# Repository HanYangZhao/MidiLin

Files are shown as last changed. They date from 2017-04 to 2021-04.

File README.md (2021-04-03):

# Arduino Midi Ribbon Controller

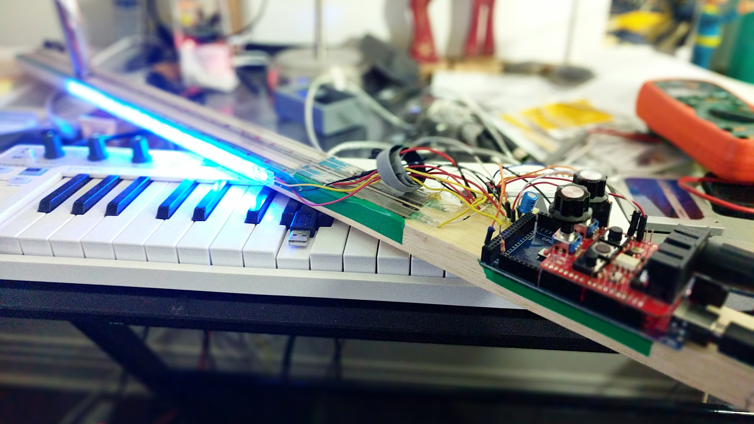
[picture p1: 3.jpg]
Demo (https://www.youtube.com/watch?v=UU3WkZmNJEc)


This project was inspired by Wintergatan's Modulin https://www.youtube.com/watch?v=MUdWeBYe3GY

## Features

* 2 x 24 quantized notes on a 50cm long neck
* Able to switch between all 7 music modes while retaining quantization
* +/- Semitone Tranpose and +/- Octave Tranpose
* Finger pressure controls modulation
* Volume controllable by adjusting the pot at the end of the neck
* LED reacts to finger position
* Pitchbend by using the analog stick

[Demo](https://youtu.be/UU3WkZmNJEc)

## Main components

* [2 x Softpot Membrane](https://www.sparkfun.com/products/8681)
* [2 x Force Sensitive Resistor](https://www.sparkfun.com/products/9674)
* 1 x Arduino Mega
* [1 x Sparkfun Midi Shield](https://www.sparkfun.com/products/12898)
* 1 x 10K pot (volume control)
* 1 x 1M 60LED Neopixel
* 1 x Analog Joystick (pitchbend)

Theory by : https://synthhacker.blogspot.ca/2016/03/diy-midi-ribbon-controller.html
Code adapted from https://github.com/deanm1278/arduinoRibbonController/blob/master/synth_v3.ino

## Schematics 
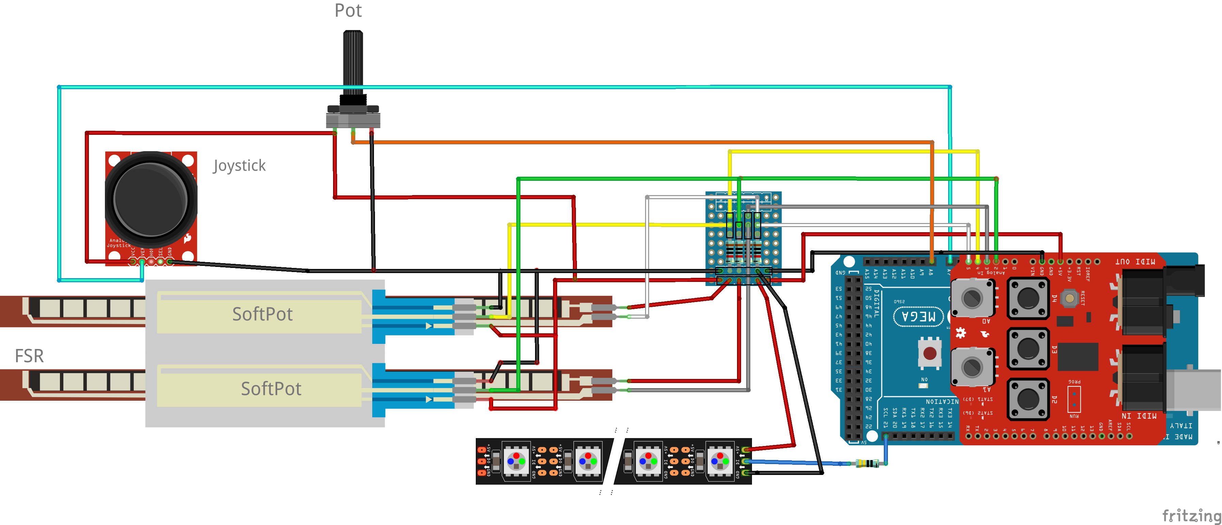
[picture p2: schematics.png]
Schematics


Note : In the prototyping board, all nodes in a black rectangle are connected together

Note : The softpots are placed over the force sensitive resistors ( see picture below)

### Pins connection

* Softpots : A4,A2
* FSRs : A5,A3
* Pot : A8
* Analog Stick : A7
* Neopixel : D21

### First time calibration
* Set the A0 potentiometer all the way down on the midi shield.
* Uncomment Serial.begin(115200) and comment Serial.begin(31250);
* Uncomment calibrate() at line 168
* To calibrate the softpots, open a serial console. When it says "waiting" press on one of the softstick and set the A0 potentiometer up on the midi shield. Once you see the confirmation in the console output turn it back down and proceed back to the next fret. Repeat for N_FRET times and repeat the same for the second softpot. When it's done the program will write the calibration in to the EEPROM and you may comment the line 168 and switch the serial to 31250 baud again. 
* The notes that are close to the Arduino are lower

## Manual
* Semitone Transpose : Pressing one of black buttons on the midi shield will transpose up and the other black button will transpose down
* Octave Transpose : Pressing the middle button AND one of the black button with do an octave transpose
* Change musical mode : Turning the "lower" knob will change the music mode. When switching modes, the LEDs will light up according the mode you've chosen (1-7)
* You need to twist the "upper" knob all the way up for it to work. This is a bug
* Change volume : use the volume knob at the end of the stick
* Pitch bend : Use the analog stick for pitchben
* Modulation : Modulation is controlled by how hard you press on the stick, the harder you press the more modulation.
* The midi out of the midi shield need to be plugged into your audio interface/midi converter
* Power the Arduino either by pluggin the USB cable or through battery

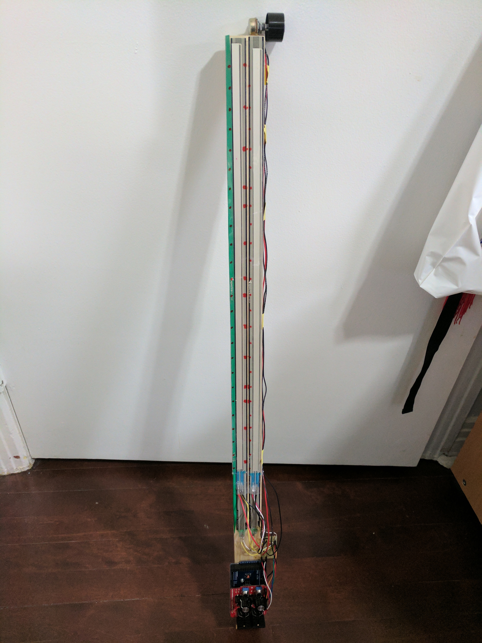
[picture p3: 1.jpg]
Complete

Closeup

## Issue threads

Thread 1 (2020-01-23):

Help needed, troubleshooting the Midilin

apandypy777, 2020-01-23:
Hi @HanYangZhao ,

Thanks for this great GitHub, I have built my own Midilin but need some help making it work.

**My setup:**
I am using a prototyping board at the moment before making the final assembly.
Note that I am only using one ribbon at the moment (I broke the other one while soldering >.<)

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

**The issues:**
1. When I calibrate the SoftPot, I follow the first time calibration instructions and upload the code to the arduino (with MIDI shield switch in PROG mode). Everything seems fine, however To calibrate each fret instead of using the middle button of the MIDI shield i have to use the A0 knob instead and turn it from counter clockwise and then clockwise to write each address, i think this is a first sign that something is wrong in my setup.
I get this messages on my serial:

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

**After calibrating the 50 frets, some strange symbols appear.**

At this point I am not sure what to do next. What I did is re-comment the Calibrate lines, re-upload the "original" code and finally switch the MIDI shield to RUN.

I tried to connect to Ableton using the Synth 1 plugin you recommended. Ableton recognizes there is a new MIDI input, however no signals are received from it and therefore no music is being played.

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

My USB to MIDI cable
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

Please let me know if you notice something that could be the problem in my setup.
Thank you in advance!

Andy

HanYangZhao, 2020-01-27:
Hm I checked the code again, it didn't seem like you need to press a button or turn a knob when you calibrate. You might need to A0 in the beginning but not everytime. Have you tried calibrating with less frets?

apandypy777, 2021-03-06:
My friend Marek Narozniak help me to fix this issue:

Before the calibration we needed to set the A0 knob all the way down. The middle button didn't confirm the positions, its the A0 knob. During the calibration we need to confirm pressing by turning the A0 knob all the way up.

Programming the uC must be done without the MIDI shield.

Closed 2021-03-06.

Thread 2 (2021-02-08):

Variable name meanings

davinderc, 2021-02-08:
Hi, my apologies for getting in touch via Issues, but I found it to be the most relevant way. I'm reading through your code so I can adapt it to create a digital modulin (including synthesizer). I'm currently stuck at calibrating because my soldering iron and parts are far away at home, so I'm just trying to work on the code as much as possible.

What are the T_vals (and other T_- prefixed variables) and S_vals (and other S_- prefixed variables)?

HanYangZhao, 2021-02-09:
Hi,

It's been a long time since I've original wrote the code so my memory is somewhat fuzzy. But from a quick read the T_vals are related to check of notes are being triggered when pressing on the ribbon sensor. The S_vals are related to the midi note number themselves

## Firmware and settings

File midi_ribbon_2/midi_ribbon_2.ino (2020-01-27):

/*
* Arduino Ribbon Synth MIDI controller
* ------------------------------------
* ©2015 Dean Miller
* Modified by hyz
*/

#include <EEPROM.h>
#include <Wire.h>
#include <Adafruit_NeoPixel.h>
#include <QuickStats.h>
#ifdef __AVR__
  #include <avr/power.h>
#endif

#define PIN_LED   13
#define NEO_PIN   21
#define N_PIXELS  29      //# of LEDS
#define TRANSPOSE_UP 4    //D4
#define TRANSPOSE_DOWN 2  //D2
#define VOLUME    A8      //Master volume
#define MODAL     A1      //Switch between the 7 musical modes
#define S0        A2      //String 0
#define M0        A3      //Modulation 0
#define S1        A4      //String 1
#define M1        A5      //Modulation 1

/*Here for legacy*/
#define T0        A0
#define T1        A0
#define T2        A0
#define T3        A0

#define JSX       A7
#define JSY       A6

//#define JSSEL     7


#define THRESH    600
#define N_STR     2
#define N_FRET    25
#define S_PAD     3
#define T_PAD     300

#define MOD_THRESHOLD 30  //Modulation is not send under this value

//---Midi CC----
#define VOLUME_CC 7
#define MOD_CC 1
#define MIDI_CHANNEL 0
#define VOLCA_VOLUME_CC 11
#define VOLCA_MOD_CC 46
#define VOLCA_MIDI_CHANNEL 10
#define MUTE_CC 123 

long noteDebounceTime = 0;
int noteDebounceDelay = 25;

long lastDebounceTime = 0;
int debounceDelay = 200;

long ledDebounceTime = 0;
int ledDebounceDelay = 20;

short fretDefs[N_STR][N_FRET];

int mod_final;
int vol;
int vol_buffer;
int modal;
int modal_buffer;
int buffer_mod[2];
int mod[2];
int mod_init[2]; //initial values for modulation
int s_init[2];   //intial values for string position
int pre_vol;     //previous volume
int pre_mod;     //previous modulation
bool volca = false;
int volume_cc = VOLUME_CC;
int mod_cc = MOD_CC;
int channel = MIDI_CHANNEL;
bool isPitchBend = false;
unsigned int pitchBendLight = 0;
bool dim = false;


int modal_array [6][7] =  {{0,2,4,5,7,9,11},   //ionian
                           {0,2,3,5,7,9,10},   //dorian
                           {0,1,3,5,7,8,10},   //phyrgian
                           {0,2,4,6,7,9,11},   //lydian
                           {0,2,4,5,7,9,10},   //mxyolydian
                           {0,2,3,5,7,8,10}};    //aeolian
                           //{0,1,3,5,6,8,10}};

short T_vals[N_STR];
bool T_active[] = {false, false, false, false}; //is it currently active
short T_hit[N_STR];                             //has it been hit on this loop
int T_pins[] = {T0, T1, T2, T3};

short S_vals[N_STR];                            //current sensor values
short S_old[N_STR];                             //old sensor values for comparison
int S_active[N_STR];                            //currently active notes
int S_pins[] = {S0,S1};
int fretTouched[N_STR];

bool modreset = true;

//E A D G
int offsets_default[] = {40, 45, 50, 55};

//B E A D
int offsets_transposed[] = {35, 40, 45, 50};

//default offsets
int offsets[] = {40, 45, 50, 55};


Adafruit_NeoPixel pixels = Adafruit_NeoPixel(N_PIXELS, NEO_PIN, NEO_GRB + NEO_KHZ800);
int led_number[2] = {0,0};
int led_color;
int led;
int prev_led;

bool stickActive = false;
bool stickState = false;
bool btnState = false;
int stickZeroX;
int stickZeroY;

unsigned long last_read;

QuickStats stats;

void setup() {
  //read fret definitions from EEPROM
  for (int i=0; i<N_STR; i++){
    for (int j=0; j<N_FRET; j++){
      fretDefs[i][j] = EEPROMReadShort(j * sizeof(short) + (N_FRET*i*sizeof(short)));
    }
  }
  Serial.begin(31250);
  //Serial.begin(115200);
  
  for(int i=0; i<N_STR; i++){
    pinMode(T_pins[i], INPUT);
    pinMode(S_pins[i], INPUT);
  }
  
  pinMode(JSX, INPUT);
  pinMode(JSY, INPUT);
  //pinMode(JSSEL, INPUT);
  //digitalWrite(JSSEL, HIGH);

  pinMode(PIN_LED, OUTPUT);

  pixels.begin();
  pixels.setBrightness(50);
  pixels.show();
  //calibrate joystick
  stickZeroX = analogRead(JSX);
  stickZeroY = analogRead(JSY);

  //Uncomment for re-calibration. Should be done only once
  //calibrate();

  pinMode(TRANSPOSE_UP, INPUT_PULLUP);
  pinMode(TRANSPOSE_DOWN, INPUT_PULLUP);
  pinMode(A0,INPUT);
  pinMode(3,INPUT_PULLUP);
  pinMode(VOLUME,INPUT);
  pinMode(M0,INPUT);
  pinMode(M1,INPUT);
  mod_init[0] = analogRead(M0);
  mod_init[1] = analogRead(M1);
  s_init[1] = analogRead(S1);
  s_init[0] = analogRead(S0);
}

void loop() {
  readJoystick();
  readButtons();
  readModulationAndVol();
  readControls();
  determineFrets();
  legatoTest();
  pickNotes();
  cleanUp();
  delay(1);
}

void readModulationAndVol(){
  buffer_mod[0] = analogRead(M0);
  buffer_mod[1] = analogRead(M1);
  vol_buffer = analogRead(VOLUME);
  modal_buffer = analogRead(MODAL);
  modal_buffer = map(modal_buffer, 0, 700, 0, 7);
  mod[1] = map(buffer_mod[1],mod_init[1],mod_init[1]+400,0,127);
  mod[0] = map(buffer_mod[0], 500,500+300, 0, 127);
  mod_final = max(mod[0],mod[1]);
  vol = map(vol_buffer, 0, 300, 0, 127);
  if(abs(modal_buffer != modal)){
    if(modal_buffer > 7){
      modal = 7;
      modal_buffer = 7;      
    }

    else
      modal = modal_buffer;
    onLED(modal+1,0,255,0);
    delay(500);
    onLED(N_PIXELS,0,0,0);
    //Serial.println(modal);
  }
  
  if(abs(vol - pre_vol) > 1 && vol <= 127){
    //Serial.println("vol");
    if (vol >= 127)
      vol = 127;
    if (vol <= 1)
      vol = 0;
    controllerChange(volume_cc,vol);
    pre_vol = vol;
  }
  if(abs(mod_final - pre_mod) > 5){
   
    if (mod_final < MOD_THRESHOLD )
      controllerChange(mod_cc,0);
    else if ( mod_final <= 127 )
      controllerChange(mod_cc,mod_final);
       //Serial.println("mod");
    pre_mod = mod_final;    
  }
}

void readButtons(){
  int up = digitalRead(TRANSPOSE_UP);
  int down = digitalRead(TRANSPOSE_DOWN);
  int clear_notes = digitalRead(3);
  //Serial.println(up);
  if((millis() - lastDebounceTime ) > debounceDelay){
    //Serial.println("tranposeing");
    if (!down && !clear_notes)
      transpose(-2);
    else if (!up && !clear_notes)
      transpose(2);
    else if(!up && down)
      transpose(1);
    else if(!down && up)
      transpose(-1);
    else if(!up && !down){
      if(!volca){
        volume_cc = VOLCA_VOLUME_CC;
        mod_cc = VOLCA_MOD_CC;
        channel = VOLCA_MIDI_CHANNEL;
        volca = true;
        //Serial.println("volca");
      }
      else if (volca){
        volume_cc = VOLUME_CC;
        mod_cc = MOD_CC;
        channel = MIDI_CHANNEL;
        volca = false;
        //Serial.println("!volca");
      }         
    }
  
//    else if (!clear_notes){
//      controllerChange(MUTE_CC,0);
//    }
    lastDebounceTime = millis();
  }
}


void pickNotes(){
  for (int i=0; i<N_STR; i++){
    if(T_hit[i]){
      if(S_active[i]){
        //turn off active note on this string
        noteOff(0x80 + channel, S_active[i]);
        //Serial.println("picknoteoff");
      }
      if (fretTouched[i] == 1){
        noteOff(0x80 + channel, S_active[i]);
        continue;
      }
      else{
        S_active[i] = fretTouched[i] + offsets[i];
        noteOn(0x90 + channel, S_active[i], 100);
        //Serial.println("picknoteon");        
      }

    }
  }
}

void legatoTest(){
  for(int i=0; i<N_STR; i++){
    if(S_active[i]){

      int note = fretTouched[i] + offsets[i];
      if (note != S_active[i] && fretTouched[i] == -1){
        noteOff(0x80 + channel, S_active[i]);
        
        S_active[i] = note;
        //clrLED();
        continue;
        
      }

      if(note != S_active[i] && (fretTouched[i] || T_active[i])){
        //Serial.println("legatonote");
        int volume = mod_final * 2;
        if(volume > 127)
          volume = 127;
        noteOn(0x90 + channel, note, 127);
        noteOff(0x80 + channel, S_active[i]);
        S_active[i] = note;
      }
    }
  }

  led = max(led_number[0],led_number[1]);
  //Serial.println(led_number[0]);
   //Serial.println(led_number[1]);
  if (led == -1){
    led = 0;
    onLED(N_PIXELS,0,0,0);
  }
    
  else{
    led = led + 1;
    led = map(led,0,N_FRET - 1,0,N_PIXELS);
    led_color = map(led,0,30,0,255);
    //Serial.println(led_number);
    if((millis() - ledDebounceTime ) > ledDebounceDelay){
      for(int i=0;i<led;i++){
        //pixels.Color takes RGB values, from 0,0,0 up to 255,255,255
        pixels.setPixelColor(i, Wheel(led_color));
      }
      if(prev_led > led)
        for(int i=led;i<N_PIXELS;i++){
          //pixels.Color takes RGB values, from 0,0,0 up to 255,255,255
          pixels.setPixelColor(i, (pixels.Color(0, 0, 0)));
        }
        pixels.show();
        ledDebounceTime = millis(); 
        prev_led = led ;
    }
  }
}

void cleanUp(){
  for (int i=0; i<N_STR; i++){
    if(S_active[i] && !fretTouched[i] && !T_active[i]){
        noteOff(0x80 + channel, S_active[i]);
        S_active[i] = 0;
    }
  }
}

void readControls(){
  //read the strings and the triggers
  for (int i=0; i<N_STR; i++){
    T_hit[i] = checkTriggered(i);
    //Serial.println(T_hit[i]);
    //if(i == 1 && abs(buffer_mod[i] - mod_init[i] > 1)){
    float temp[3];
    for (int k = 0 ; k < 3; k++){
      temp[k] = analogRead(S_pins[i]);
      delay(3);
    }
     S_vals[i] = stats.minimum(temp,3);
  }
}

void determineFrets () {
 //---------Get Fret Numbers------
 for (int i=0; i< N_STR; i++) {
   
   short s_val = S_vals[i];
   
    //check for open strings
   if (s_val == 0 ) {
    S_old[i] = s_val;
    fretTouched[i]=-1;
    led_number[i] = fretTouched[i];
  }

  else{
      //loop through the array of fret definitions
    for (int j=1; j<N_FRET; j++) {
      int k = j - 1;
      if (s_val >= fretDefs[i][j] && 
        s_val < fretDefs[i][k] &&
      abs((int)s_val-(int)S_old[i]) > S_PAD) {
        
        S_old[i] = s_val;
        fretTouched[i] = j - 1;
        led_number[i] = fretTouched[i];
        if(modal < 7){
          // not chromatic mode
          if(i == 0) 
            fretTouched[i] = modal_array[modal][fretTouched[i]%7] + (fretTouched[i]/7) * 12;
          else if(i == 1)
          {
             if(modal == 3)
              fretTouched[i] = (modal_array[(modal+3)%6][fretTouched[i]%7] + (fretTouched[i]/7) * 12) + 2; //fix for locrian
             else if(modal > 3){
              fretTouched[i] = (modal_array[(modal+2)%6][fretTouched[i]%7] + (fretTouched[i]/7) * 12);
             }
             else{
              fretTouched[i] = modal_array[(modal+3)%6][fretTouched[i]%7] + (fretTouched[i]/7) * 12;
             }
          }

        }          
//        Serial.println("fret");
//        Serial.println(i);
//        Serial.println(fretTouched[i]);
//        Serial.println("");
       }
     }
   }
 }

}


void unset(int i){
  //this function doesn't even do anything!!
}



void calibrate(){
  if (1) {
  int btn = 1;
  Serial.println("calibrating...");
  for (int i=0; i<N_STR; i++) {
    //Flash the LED too indicate calibration
    onLED(10,250,0,0);
    delay(100);
    clrLED();
    onLED(10,250,0,0);
    delay(100);
    clrLED();
    onLED(10,250,0,0);
    delay(100);
    clrLED();
  
    short sensorMax = 0;
    short sensorMin = 1023;
    short val;
    
    //loop through the array of fret definitions
    for (int j=N_FRET - 1; j>=0; j--) {
      int response = false;
      //wait for response
      Serial.println("waiting");
      while (!response) { 
        if (checkTriggered(i)) {
          val = (analogRead(S_pins[i]));
          response = true;
          //write to memory
          clrLED();
          int addr = j * sizeof(short) + (N_FRET*i*sizeof(short));
          Serial.print("Writing ");
          Serial.print(val);
          Serial.print(" to address: ");
          Serial.println(addr);
          EEPROMWriteShort(addr, val);
        }
        delay(10);
      } 
      delay(100);
      onLED(10,250,0,0);
    }
    for (int j=0; j<N_FRET; j++) {
      short v = EEPROMReadShort(j * sizeof(short) + (N_FRET*i*sizeof(short)));
      fretDefs[i][j] = v;
    }
  }
  clrLED();
  }
}

void EEPROMWriteShort(int address, int value){
  //One = Most significant -> Two = Least significant byte
  byte two = (value & 0xFF);
  byte one = ((value >> 8) & 0xFF);

  //Write the 4 bytes into the eeprom memory.
  EEPROM.write(address, two);
  EEPROM.write(address + 1, one);
}

short EEPROMReadShort(int address){
  //Read the 2 bytes from the eeprom memory.
  long two = EEPROM.read(address);
  long one = EEPROM.read(address + 1);

  //Return the recomposed short by using bitshift.
  return ((two << 0) & 0xFF) + ((one << 8) & 0xFFFF);
}

void onLED(int led,int red,int green, int blue){
  for(int i=0;i<led;i++){
    //pixels.Color takes RGB values, from 0,0,0 up to 255,255,255
    pixels.setPixelColor(i, pixels.Color(red, green, blue));
  }
  pixels.show();
}

void clrLED(){
  for(int i=0;i<N_PIXELS;i++){
    pixels.setPixelColor(i, pixels.Color(0,0,0)); // turn off
  }
  pixels.show();
}

//check if a trigger has been hit. Return 0 if not, the value of the trigger if it has
short checkTriggered(int i){
  
  short v = analogRead(T_pins[i]);
  //Serial.println(v);
  T_vals[i] = v;
  short ret = 0;
  if(!T_active[i] && v > THRESH){
    T_active[i] = true;
    ret = v;
    //Serial.println("triggered");
  }
  else if(T_active[i] && v < THRESH - T_PAD){
    T_active[i] = false;
    //Serial.println("un-triggered");
  }
  //Serial.println(ret);
  return ret;
}

void transpose(int dir){
  switch(dir){
    case 1:
      for (int i=0; i<N_STR; i++) {
        offsets[i] = offsets[i] + 1;
        //Serial.println(offsets[0]);
      }
      break;
  
    case -1:
      for (int i=0; i<N_STR; i++) {
        offsets[i] = offsets[i] - 1;
        //Serial.println(offsets[0]);
      }
      break;
   case 2:
      for (int i=0; i<N_STR; i++) {
        offsets[i] = offsets[i] + 12;
        //Serial.println(offsets[0]);
      }
      break;
   case -2:
      for (int i=0; i<N_STR; i++) {
        offsets[i] = offsets[i] - 12;
        //Serial.println(offsets[0]);
      }
      break;   
  }
}

void readJoystick(){
  unsigned int joyx = analogRead(JSX);
  pitchBendLight = (abs(joyx - 512) / 10);
  if(abs(joyx - 512) > 15){
    isPitchBend = true;
    PitchWheelChange(map(joyx,0, 1023, -8192, 8180));
  }
  else if(isPitchBend){
    PitchWheelChange(512);
    isPitchBend = false;  
  }
}

//note-on message
void noteOn(int cmd, int pitch, int velocity) {
  
  Serial.write(byte(cmd));
  Serial.write(byte(pitch));
  Serial.write(byte(velocity));
  Serial.flush();
  digitalWrite(PIN_LED, HIGH);
}
//note-off message
void noteOff(int cmd, int pitch) {
  
  Serial.write(byte(cmd));
  Serial.write(byte(pitch));
  Serial.write(byte(0));
  Serial.flush();
  digitalWrite(PIN_LED, LOW);
}

//Sends controller change to the specified controller
void controllerChange(int controller, int value) {
  //Serial.println("cc");
  int ch = 176 + channel;
  Serial.write(byte(ch));
  Serial.write(byte(controller));
  Serial.write(byte(value));
  Serial.flush();
}



// Input a value 0 to 255 to get a color value.
// The colours are a transition r - g - b - back to r.
uint32_t Wheel(byte WheelPos) {
  WheelPos = 255 - WheelPos;
  if(WheelPos < 85) {
    return pixels.Color(255 - WheelPos * 3 + pitchBendLight, 0, WheelPos * 3 + pitchBendLight);
  }
  if(WheelPos < 170) {
    WheelPos -= 85;
    return pixels.Color(0, WheelPos * 3 + pitchBendLight , 255 - WheelPos * 3 + pitchBendLight);
  }
  else{
    WheelPos -= 170;
    return pixels.Color(WheelPos * 3 + pitchBendLight , 255 - WheelPos * 3 + pitchBendLight , 0 );
  }
  if(mod_final> 50){
  }
}


void PitchWheelChange(int value) {
  unsigned int change = 0x2000 + value;  //  0x2000 == No Change
  unsigned char low = change & 0x7F;  // Low 7 bits
  unsigned char high = (change >> 7) & 0x7F;  // High 7 bits

  Serial.write(0xE0);
  Serial.write(low);
  Serial.write(high);
  Serial.flush();
}

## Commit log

2017-04-28 Added leds
2017-04-28 fixed a few bugs
    [midi_ribbon_2.ino]
2018-02-14 added schematics
    [schematics.fzz]
2018-02-14 updated schematics
    [schematics.fzz]
2018-02-14 fixed small bug in the schematics
    [schematics.fzz]
2018-03-07 updated shematics
    [schematics.fzz]
2021-03-10 Update README.md
    Outdated calibration description, not consistent with the source.
